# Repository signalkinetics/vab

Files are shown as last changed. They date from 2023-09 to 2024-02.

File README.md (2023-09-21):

# Enabling Long-Range Underwater Backscatter via Van Atta Acoustic Networks

We present the design, implementation, and evaluation of Van Atta Acoustic Backscatter (VAB), a technology that enables long-range, ultra-low-power networking in underwater environments. At the core of VAB is a novel, scalable underwater backscatter architecture that bridges recent advances in RF backscatter (Van Atta architectures) with ultra-low-power underwater acoustic networks. Our design introduces multiple innovations across the networking stack, which enable it to overcome unique challenges that arise from the electro-mechanical properties of underwater backscatter and the challenging nature of low-power underwater acoustic channels. We implemented our design in an end-to-end system, and evaluated it in over 1,500 real-world experimental trials in a river and the ocean. Our evaluation demonstrates that VAB achieves a communication range that exceeds 300m in round trip backscatter across orientations (at BER of $10^{-3})$. We compared our design head-to-head with past state-of-the-art systems, demonstrating a $15\times$ improvement in communication range at the same throughput and power. By realizing hundreds of meters of range in underwater backscatter, this paper presents the first practical system capable of coastal monitoring applications. Finally, our evaluation represents the first experimental validation of underwater backscatter in the ocean. 

<figure>
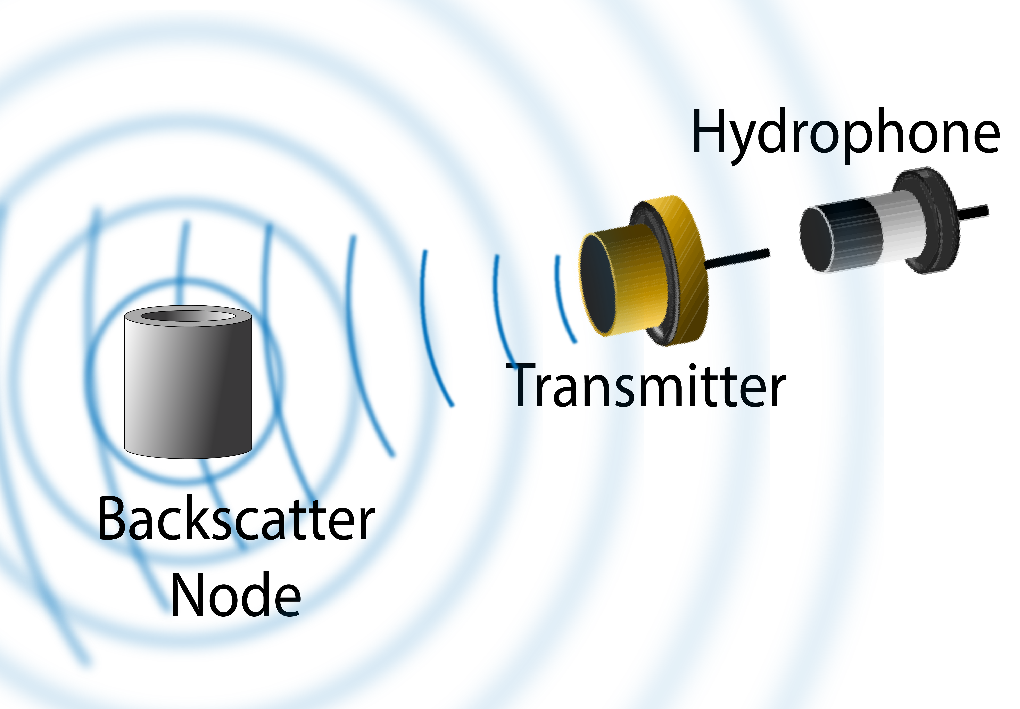
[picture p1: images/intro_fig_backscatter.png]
    
    <figcaption style="text-align: center;"><strong>Traditional Underwater Backcsatter</strong></figcaption>
</figure>

<figure>
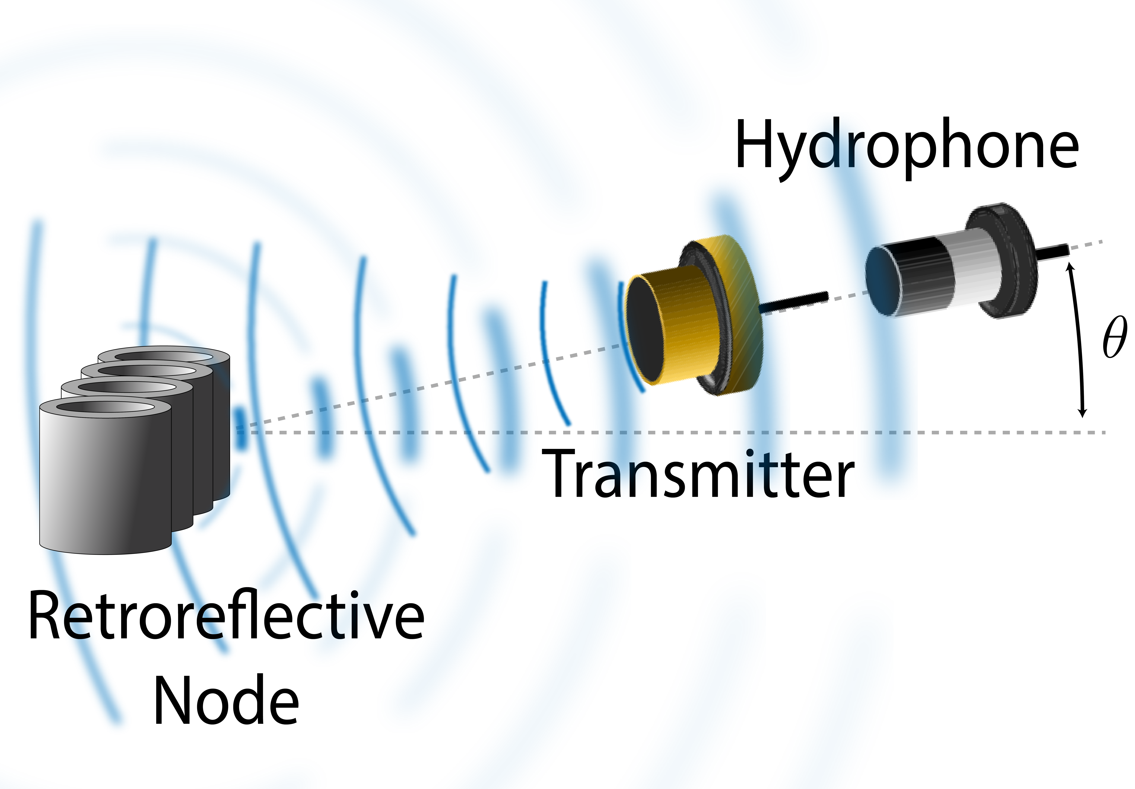
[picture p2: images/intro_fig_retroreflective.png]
    
    <figcaption style="text-align: center;"><strong>Our Retroreflective Design</strong></figcaption>
</figure>

<br>This work builds on the work of [Underwater Backscatter](https://github.com/saadafzal24/Underwater-Backscatter), and contains a number of important improvements to the piezoelectric nodes, decoding pipeline, and most importantly the backscatter device architecture. 

## Contents

The repository is organized into the components that make up a full experimental VAB system:

- **Van Atta Array** (`vanatta`): Contains the simulation tools for a Van Atta array.
- **Transmitter / Reader** (`txrx`): Contains the source code for the transmit and receive pipelines in VAB, including the core multichannel DFE implementation. 
- **Piezoelectric Nodes** (`node`): Contains 3D models and hardware design files for the piezoelectric node manufacturing process. These nodes are used in the transmitter and the Van Atta array. 

### Datasets

Datasets can be found under the corresponding wiki page. Unless otherwise specified, all datasets have a sampling rate of 44.1 kHz. 

## Getting Started

The best immediate first step would be to reproduce the paper results from the datasets using the multichannel DFE pipeline in the `txrx` folder. The remaining system components must be built and thus the development time is much longer. 

## Acknowledgement

**Authors**: [Aline Eid](https://alineeid.engin.umich.edu/), [Jack Rademacher](https://jackrademacher.me), [Waleed Akbar](https://signal-kinetics.media.mit.edu/people/waleed-akbar/), [Purui Wang](https://signal-kinetics.media.mit.edu/people/purui-wang/), [Ahmed Allam](https://ahmed-allam.com/), Fadel Adib

**Advisor/PI**: [Fadel Adib](http://www.mit.edu/~fadel/)

**Paper**: https://dl.acm.org/doi/10.1145/3603269.3604814

Cite the paper using BibTex as follows:

```
@inproceedings{10.1145/3603269.3604814,
author = {Eid, Aline and Rademacher, Jack and Akbar, Waleed and Wang, Purui and Allam, Ahmed and Adib, Fadel},
title = {Enabling Long-Range Underwater Backscatter via Van Atta Acoustic Networks},
year = {2023},
isbn = {9798400702365},
publisher = {Association for Computing Machinery},
address = {New York, NY, USA},
url = {https://doi.org/10.1145/3603269.3604814},
doi = {10.1145/3603269.3604814},
abstract = {We present the design, implementation, and evaluation of Van Atta Acoustic Backscatter (VAB), a technology that enables long-range, ultra-low-power networking in underwater environments. At the core of VAB is a novel, scalable underwater backscatter architecture that bridges recent advances in RF backscatter (Van Atta architectures) with ultra-low-power underwater acoustic networks. Our design introduces multiple innovations across the networking stack, which enable it to overcome unique challenges that arise from the electro-mechanical properties of underwater backscatter and the challenging nature of low-power underwater acoustic channels. We implemented our design in an end-to-end system, and evaluated it in over 1,500 real-world experimental trials in a river and the ocean. Our evaluation in stationary setups demonstrates that VAB achieves a communication range that exceeds 300m in round trip backscatter across orientations (at BER of 10−3). We compared our design head-to-head with past state-of-the-art systems, demonstrating a 15\texttimes{} improvement in communication range at the same throughput and power. By realizing hundreds of meters of range in underwater backscatter, this paper presents the first practical system capable of coastal monitoring applications. Finally, our evaluation represents the first experimental validation of underwater backscatter in the ocean.},
booktitle = {Proceedings of the ACM SIGCOMM 2023 Conference},
pages = {1–19},
numpages = {19},
keywords = {ocean IoT, underwater sensing, retrodirective structures, van atta, backscatter communications, piezo-acoustic backscatter},
location = {New York, NY, USA},
series = {ACM SIGCOMM '23}
}
```

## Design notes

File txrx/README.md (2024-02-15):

# Concepts
## MSK
Continuous phase, progress by $+\pi/2$, or $-\pi/2$ per bit
## FM0
For each bit,  flip the output polarity once (bit 1, $\pm\pi$, ) or twice (bit 0, $\pm2\pi$)

## MSK+Subcarrier
For each bit, flip N times to represent 1, or flip N+1 times to represent 0.

## OQPSK representation of MSK
OQPSK modulation: shift every other BPSK symbol by $\pi/2$ phase ($\times1j$). The  phase change between symbols is then $\pi/2$ or $-\pi/2$.

 Convolve an OQPSK impulse train with a two-symbol half-sine pulse will result in a MSK waveform, with the new  i-th MSK bits as the XOR of $(i-1)$-th and $i$-th OQPSK bit, because OQPSK is in absolute phase but MSK is in phase difference (i.e. frequency).

That is to say, if the transmitter does XOR precoding to modify the source before sending to MSK(FM0 or subcarrier) encoder, the information will be in the OQPSK format and information is encoded in **absolute phase**. The benefit of use such precoding is that it drops the phase continuity constraint in FM0 that doubles the BER at the same SNR compared to OQPSK.

## OQPSK decode pipeline (SPB : #sample per bit):
1. Matched filter of the half-sine pulse
2. Noise-whitening of the previous match filter step: IIR H(z)=1/(1+0.359z^(-SPB))
3. Modulate with exp(-1j / SPB * pi / 2), this converts the OQPSK back to BPSK
4. Feed to a vanilla BPSK DFE equalizer.

# How to Compile
The equalization operates on the square root of the covariance matrics, which is supported via C++/Eigen's Cholesky module. Therefore, the equalization needs to compile the underlying `linreg_mc.cpp` in order to function properly.

Currently, the supported platform are Ubuntu 20.04 and 22.04, X86-64. (ARM machines, especially the Apple silicon Macs are not supported) On those machines you may
```bash
(cd src; make)
```
and the `linreg_mc.so` will be compiled, so the `equalization.py` can call it properly.

# Code structure
`` scfde.py`` single carrier frequency domain equalization

`` equalization.py `` : Time domain equalization, accepts BPSK data or the preprocessed single-sideband MSK data from `msk.py`

`` msk.py `` MSK half-sine match filter and whiten filter. The subcarrier is not maintained and should instead be handled by ``mixer_cfo`` in linregs.py. After the pre-processing it should become BPSK samples and handled by `equalization.py`. The Viterbi decoder was intended for single-tap channel and isn't useful/maintained. 

`` linregs.py `` mixer function, linear regression for single and multiple channel single-tap preamble alignment

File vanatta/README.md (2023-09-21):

# SK Piezoelectric Backscatter Van Atta

The Van Atta is a specialized antenna array first created for the RF domain in 1955. It is a retroreflective structure, in that it reflects an incoming wave back in the same direction that it came from. You can view the original patent [here](https://patents.google.com/patent/US2908002A/en).

This project is an extension of the Van Atta array to piezoelectric devices in the underwater acoustic domain. The method is effectively the same, but there are unique challenges specific to piezoelectric devices, specifically maximum power transfer matching. Our group's derivations for far field beam patterns and maximum power transfer matching are given in [this document](https://drive.google.com/file/d/1DULdc8UHSOuENSTepJ27DRMAoALPb1Ii/view?usp=sharing).

## Installation

Visit our [How to Set-Up USRP Tutorial](https://docs.google.com/document/d/1ePhpxb1y15XBV4cvTJPKnmYtWSkvokSHL-_EcKC4X9U/edit) for UHD build, installation, and getting started instructions. Installing this repo is a prerequisite for compiling the C++ sources that control the USRP. 

Once UHD has been `make`'d and `sudo make install`'d in a separate directory, if installing for the first time, run: <br>
`mkdir build && cd build && cmake ../ && make -j` <br>

The binaries will be built into executables in the build folder.  

## Use

#### `/src/matlab/get_sparams.m`

Converts a node RLC model into the equivalent 2-port network S-parameters. The derivation of this code is shown in the theory document above. 

#### `/src/matlab/impedance_read.m`

A small snippet to read impedance CSVs and plot them. 

#### `/src/matlab/rlc_modeler.m`

Uses a least-squares algorithm to model the impedance of a node as an equivalent RLC, and provides the R, L, and C values that best fit the impedance. Needs to be run a couple times before convergence.

#### `/src/matlab/spectrogram_plot.m`

An unfinished piece of spectrogram code. Mostly unused.

#### `/src/matlab/subcarrier_extractor.m`

Accepts datasets with backscatter peaks next to the carrier. Extracts their location based on a provided modulation frequency and averages their power across multiple trials and angles of rotation.

#### `/src/matlab/subcarrier_extractor_baseband.m`

Similar to the subcarrier extractor, except this code provides filtering and downconversion, and then computes an SNR-like metric for received backscatter power. 

#### `/src/matlab/van_atta_beam_patterns.m`

Computes a theoretical van atta beam pattern based on the theory given in the document above. Incorporates computation of S-parameters and their effect on the pattern. Accepts node RLC models and array parameters such as element spacing, frequency, element number, and angle of incidence. Plots the received pattern for two different modes of array pattern and direction pattern. 

#### `/src/c/rx_multi_samples.cpp`

A modified UHD source that connects to multiple USRPs and places each channel into the real and imaginary part of the .dat file

## Datasets

Datasets for measured node [impedances](https://drive.google.com/drive/u/1/folders/1Lwp_WQQzYhoznev65niFUcd4ucXDke_k) and [collected backscatter measurements](https://drive.google.com/drive/u/1/folders/1og-sW82Xx33VXqlI1ZAbbL-HCPHXB5KW) are located in the google drive.

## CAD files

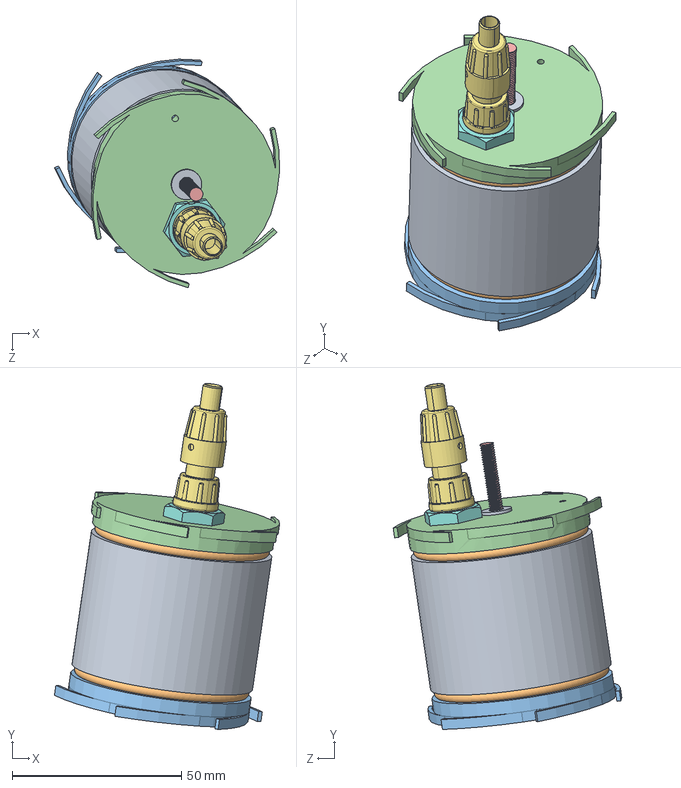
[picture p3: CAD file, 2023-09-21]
node/PAB2.SLDASM
66.6 x 102.3 x 67.6 mm
SMC5447T40111
133 Buna-N O-Ring, 50A Durometer, Round x 2
PAB2_base_spring_bottom
PAB2_base_spring_top
long_screw
17282-2PG-300_Housing.step
16282-2SG-3XX.step
17282-2PG-300_Nut.step
m4_washer

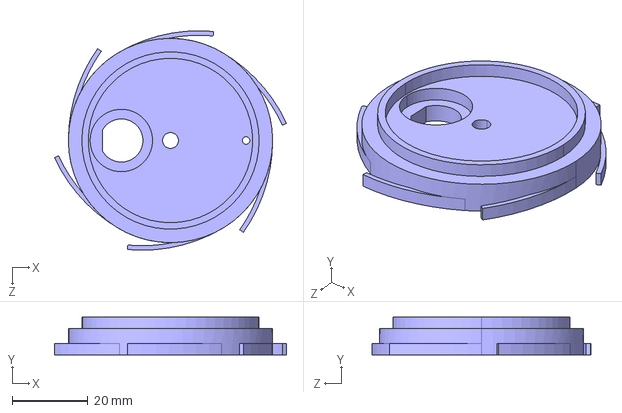
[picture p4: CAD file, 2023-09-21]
node/PAB2_base_spring_top.STEP
61.3 x 10.0 x 58.0 mm

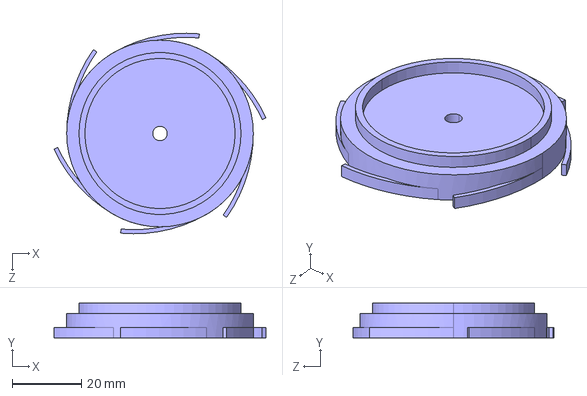
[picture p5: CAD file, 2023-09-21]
node/PAB2_base_spring_bottom.STEP
61.3 x 10.0 x 58.0 mm

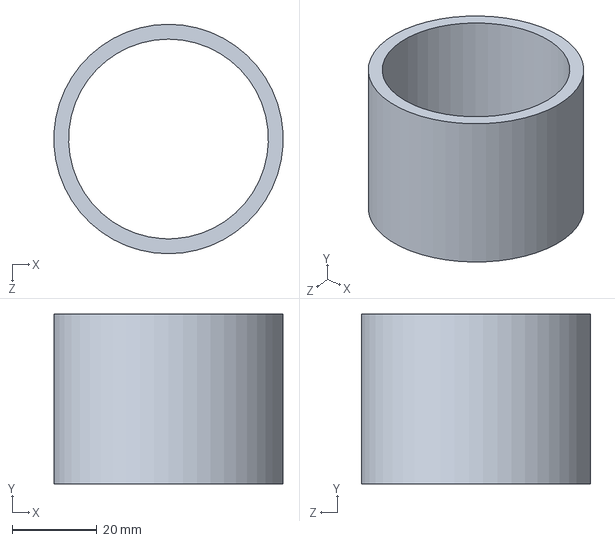
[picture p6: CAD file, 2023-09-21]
node/SMC5447T40111.SLDPRT
53.9 x 40.0 x 54.0 mm

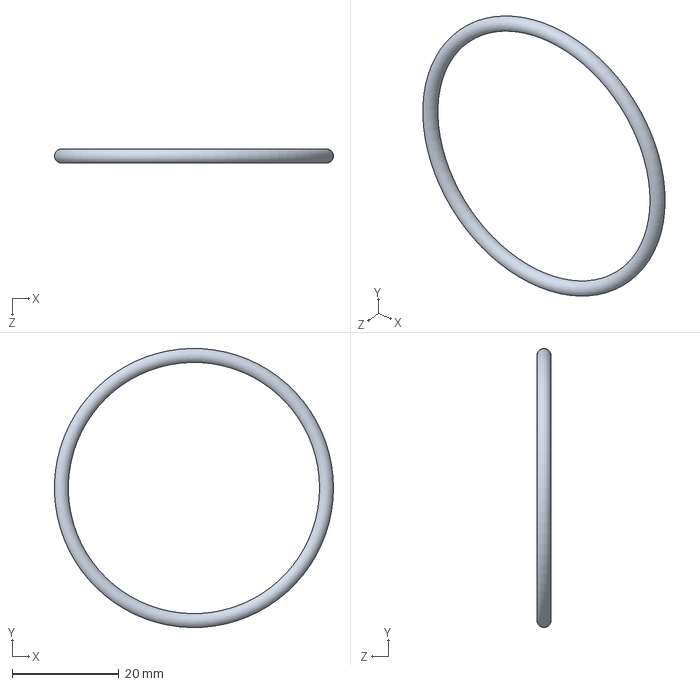
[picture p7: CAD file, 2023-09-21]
node/133 Buna-N O-Ring, 50A Durometer, Round.SLDPRT
52.2 x 52.2 x 2.62 mm

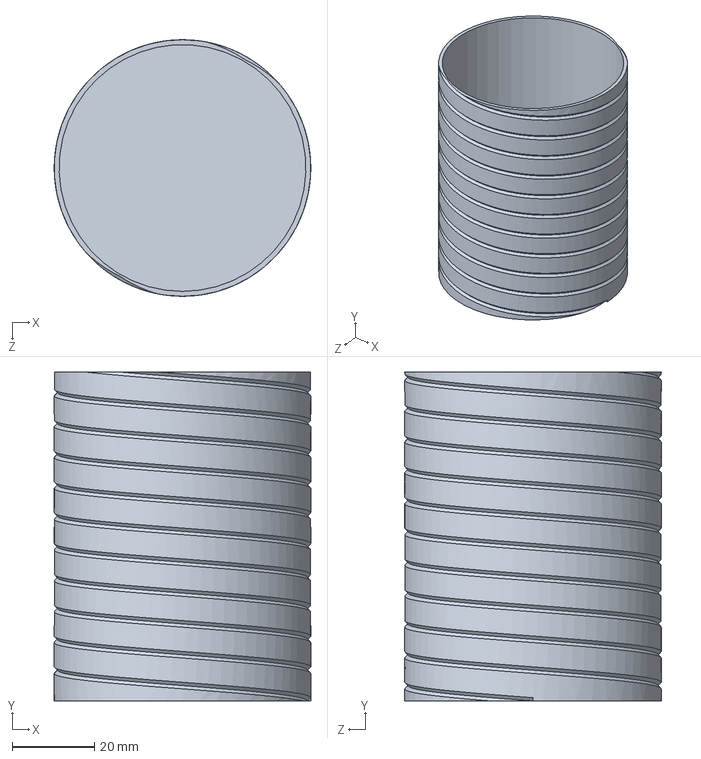
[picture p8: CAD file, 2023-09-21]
node/testhelix_6080.SLDPRT
62.4 x 80.0 x 62.4 mm

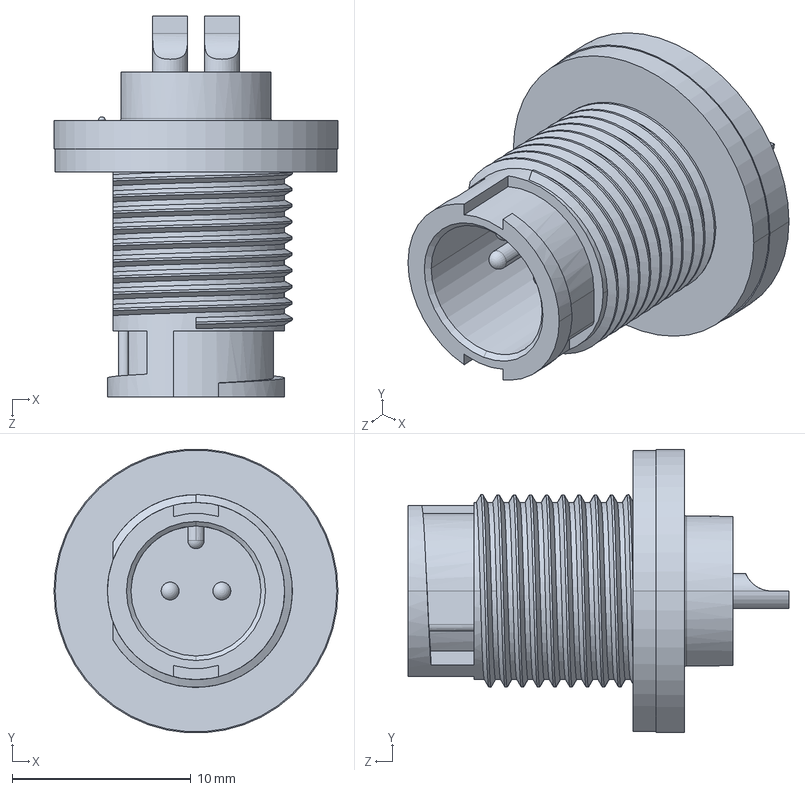
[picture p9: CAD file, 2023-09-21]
node/17282-2PG-300_Housing.step.SLDPRT
15.9 x 15.8 x 21.3 mm

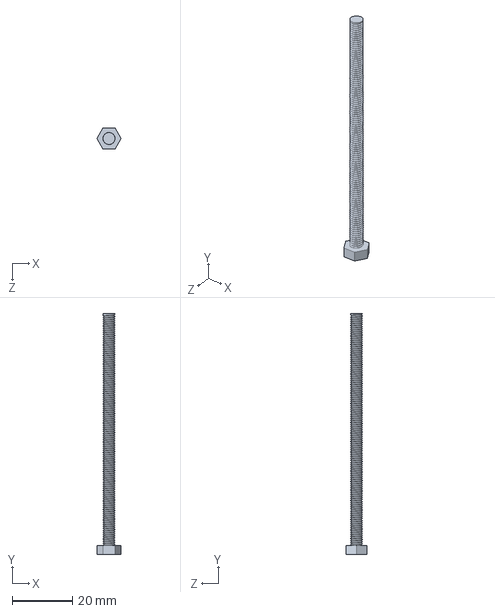
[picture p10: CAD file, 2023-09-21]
node/long_screw.SLDPRT
8.08 x 80.0 x 7.00 mm

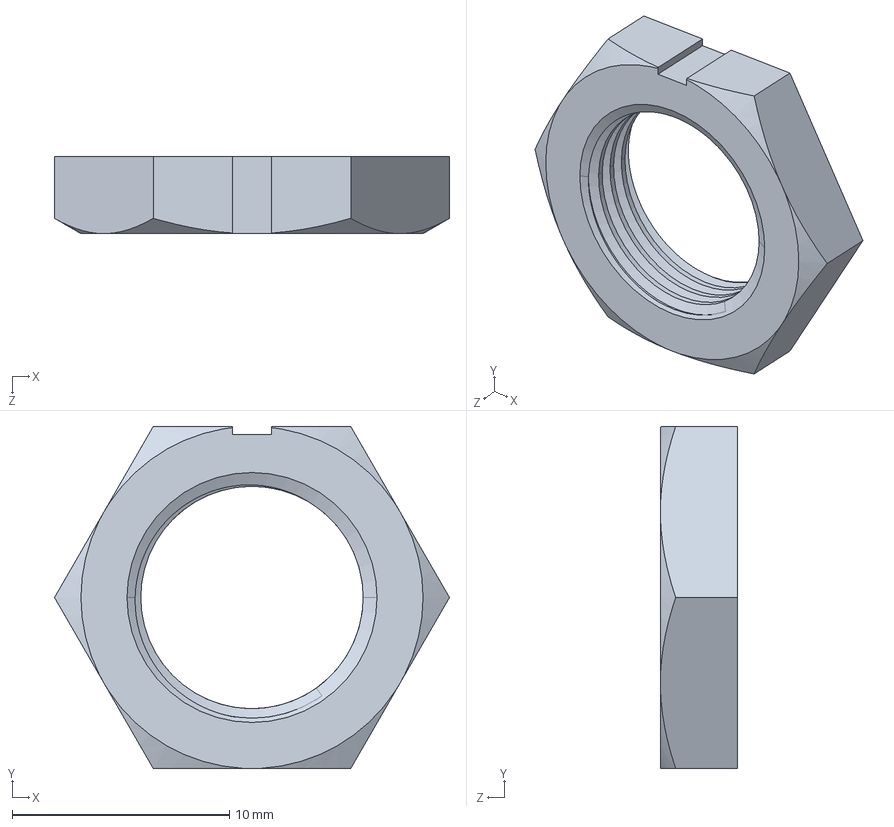
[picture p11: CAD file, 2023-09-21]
node/17282-2PG-300_Nut.step.SLDPRT
18.2 x 15.7 x 3.56 mm

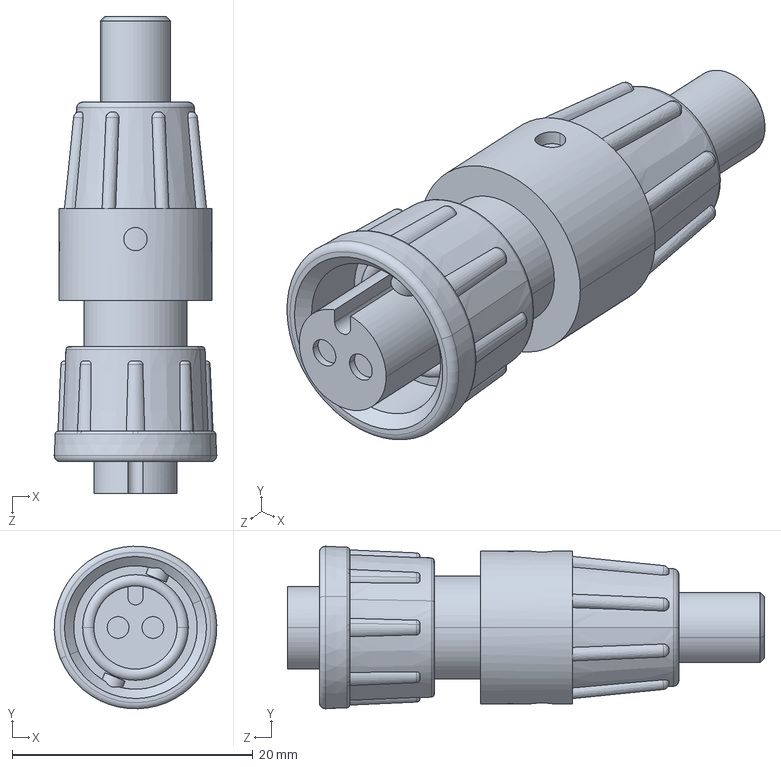
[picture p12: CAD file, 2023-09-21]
node/16282-2SG-3XX.STEP
13.5 x 13.5 x 39.6 mm

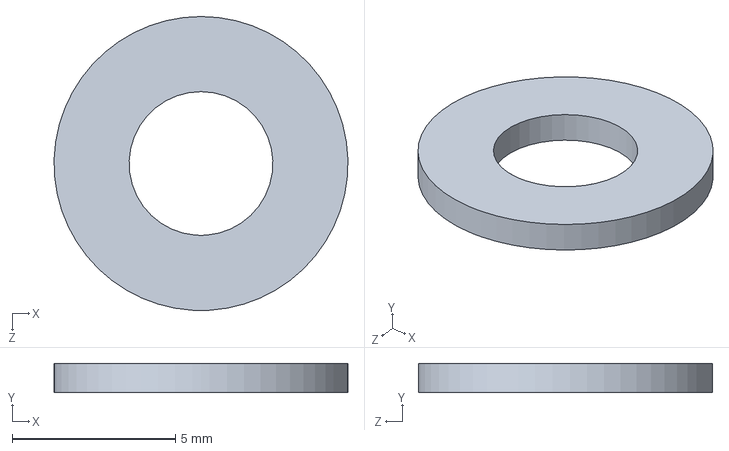
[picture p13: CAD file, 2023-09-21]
node/m4_washer.SLDPRT
9.00 x 0.9 x 9.00 mm

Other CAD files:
node/16282-2SG-3XX.SLDPRT
node/PAB2_base_spring_bottom.SLDPRT
node/PAB2_base_spring_bottom.STL
node/PAB2_base_spring_top.SLDPRT
node/PAB2_base_spring_top.STL
